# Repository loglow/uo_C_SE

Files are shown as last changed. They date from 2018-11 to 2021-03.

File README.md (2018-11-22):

# µo_C SE (uo_C, Ornament & Crime) Eurorack [Rev B]

## 8HP Eurorack module | Polymorphic CV generator

[μo_C SE](http://uoc-se.com) is a multi-purpose module in which a generic set of inputs and outputs are remapped on-the-fly through the use of a number of different built-in apps.

This re-engineered Eurorack module updates and simplifies the classic [Ornament & Crime](http://ornament-and-cri.me/) (aka o_C) design by miniaturizing the module from 14HP to 8HP and redesigning the front panel layout without eliminating any functionality.

Fully compatible with upstream o_C firmware. Includes power cable, mounting hardware, and a one-year warranty. Designed and built with care by [Tall Dog Electronics](http://tall-dog.com) in Western Massachusetts. Licensed [CC BY-NC-SA 4.0](https://creativecommons.org/licenses/by-nc-sa/4.0/) open source hardware.

- **Height:** 3U (128.5 mm)
- **Width:** 8HP (40.3 mm)
- **Depth:** 31 mm (with power)
- **+12V:** 85 mA (average)
- **-12V:** 10 mA (average)

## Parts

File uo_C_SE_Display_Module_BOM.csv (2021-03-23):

Reference | Quantity | Description | Manufacturer | Part Number | Digi-Key P/N
C1 | 1 | CAP CER 10UF 25V X5R 0805 | Taiyo Yuden | TMK212BBJ106KG-T | 587-2668-1-ND
C2 C3 C4 C5 C6 | 5 | CAP CER 2.2UF 10V X7R 0805 | Samsung | CL21B225KPFNNNE | 1276-1188-1-ND
H1 | 1 | .100" Flex Stack, High-Temp Flexible Board Stacker, Surface Mount | Samtec | HW-07-16-T-S-270-SM | N/A
H2 H3 | 2 | .100" Flex Stack, High-Temp Flexible Board Stacker, Surface Mount | Samtec | HW-03-16-T-S-270-SM | N/A
R1 | 1 | RES SMD 390K OHM 1% 1/8W 0805 | Yageo | RC0805FR-07390KL | 311-390KCRCT-ND
R2 R3 R4 | 3 | RES SMD 10K OHM 1% 1/8W 0805 | Yageo | RC0805FR-0710KL | 311-10.0KCRCT-ND
U1 | 1 | DISPLAY OLED 128X64 1.3" BLUE | WiseChip | UG-2864KSWLG03 | N/A

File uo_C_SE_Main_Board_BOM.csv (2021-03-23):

Reference | Quantity | Description | Manufacturer | Part Number | Digi-Key P/N
A1 | 1 | DISPLAY MODULE OLED | Tall Dog | TD-OCSE-B-DM | N/A
A2 | 1 | TEENSY 3.2 | PJRC | TEENSY32 | 1568-1231-ND
C1 C2 C5 C6 C7 C8 C12 C13 C14 C15 C16 C20 C21 C31 C34 | 15 | CAP CER 0.1UF 50V X7R 0603 | Samsung | CL10B104JB8NNNC | 1276-1033-1-ND
C3 C4 C9 | 3 | CAP CER 0.47UF 25V X7R 0603 | Samsung | CL10B474KA8NFNC | 1276-2082-1-ND
C10 C11 C24 C25 | 4 | CAP 10 UF 20% 25 V | Wurth Electronics | 865230440002 | 732-8259-1-ND
C17 C18 | 2 | CAP 22 UF 20% 25 V | Wurth Electronics | 865230443003 | 732-8260-1-ND
C19 C23 | 2 | CAP CER 1UF 25V X7R 0603 | Samsung | CL10B105KA8NNNC | 1276-1184-1-ND
C22 C26 C32 C33 | 4 | CAP CER 22PF 50V C0G/NP0 0603 | Samsung | CL10C220FB8NNNC | 1276-2224-1-ND
C27 C28 C29 C30 | 4 | CAP CER 560PF 50V C0G/NP0 0603 | Samsung | CL10C561JB8NNNC | 1276-1283-1-ND
D1 D2 | 2 | DIODE SCHOTTKY 40V 1A SOD123 | Diodes Incorporated | 1N5819HW-7-F | 1N5819HW-FDICT-ND
H1 | 1 | .100" Surface Mount Terminal Strip | Samtec | TSM-113-04-L-SV | N/A
H1-MATE | 1 | .100" Tiger Buy™ Low Profile Socket Strip | Samtec | SLW-113-01-L-S | N/A
H2 | 1 | .100" Surface Mount Terminal Strip | Samtec | TSM-114-04-L-SV | N/A
H2-MATE | 1 | .100" Tiger Buy™ Low Profile Socket Strip | Samtec | SLW-114-01-L-S | N/A
H3 | 1 | CONN HEADER VERT 10POS GOLD | On Shore Technology | 302-S101 | ED1543-ND
J1 J2 J3 J4 J5 J6 J7 J8 J9 J10 J11 J12 | 12 | 3.5MM JACK VERTICAL PCB MOUNT | Wenzhou QingPu | WQP-PJ398SM | N/A
L1 | 1 | FIXED IND 10UH 600MA 420 MOHM | TDK | NLCV32T-100K-PFR | 445-3654-1-ND
Q1 Q2 Q3 Q4 | 4 | TRANS NPN 40V 0.2A SOT23 | ON Semiconductor | MMBT3904LT1G | MMBT3904LT1GOSCT-ND
R1 | 1 | RES SMD 10K OHM 0.1% 1/10W 0603 | Susumu | RG1608P-103-B-T5 | RG16P10.0KBCT-ND
R2 R3 | 2 | RES SMD 47K OHM 0.1% 1/10W 0603 | Susumu | RG1608P-473-B-T5 | RG16P47.0KBCT-ND
R4 R5 | 2 | RES SMD 510 OHM 0.1% 1/10W 0603 | Susumu | RG1608P-511-B-T5 | RG16P510BCT-ND
R6 | 1 | RES SMD 2K OHM 0.1% 1/10W 0603 | Susumu | RG1608P-202-B-T5 | RG16P2.0KBCT-ND
R7 R14 R33 R34 | 4 | RES SMD 220 OHM 0.1% 1/10W 0603 | Susumu | RG1608P-221-B-T5 | RG16P220BCT-ND
R8 R21 R37 R38 | 4 | RES SMD 100K OHM 0.1% 1/10W 0603 | Susumu | RG1608P-104-B-T5 | RG16P100KBCT-ND
R9 R26 R39 R40 | 4 | RES SMD 24.9KOHM 0.1% 1/10W 0603 | Susumu | RG1608P-2492-B-T5 | RG16P24.9KBCT-ND
R10 R11 R12 R13 | 4 | RES SMD 75K OHM 0.1% 1/10W 0603 | Susumu | RG1608P-753-B-T5 | RG16P75.0KBCT-ND
R15 R16 R17 R18 R20 R28 R36 R42 | 8 | RES SMD 100K OHM 0.1% 1/10W 0603 | Susumu | RG1608P-104-B-T5 | RG16P100KBCT-ND
R19 R22 R23 R24 R25 R27 R35 R41 | 8 | RES SMD 33K OHM 0.1% 1/10W 0603 | Susumu | RG1608P-333-B-T5 | RG16P33.0KBCT-ND
R29 R30 R31 R32 | 4 | RES SMD 100 OHM 0.1% 1/10W 0603 | Susumu | RG1608P-101-B-T5 | RG16P100BCT-ND
S1 S4 | 2 | SWITCH TACTILE SPST-NO 0.05A 12V | E-Switch | TL1105DF160Q | EG1865-ND
S2 S3 | 2 | ENCODER ROTARY | Song Huei | ED1212S-24P-24C-25KC | N/A
U1 | 1 | IC DAC 16BIT QUAD-CH 16-TSSOP | Texas Instruments | DAC8565IAPW | 296-22924-5-ND
U2 | 1 | IC REG LINEAR 5V 800MA SOT223-4 | Texas Instruments | LM1117MPX-5.0/NOPB | LM1117MPX-5.0/NOPBCT-ND
U3 | 1 | IC REG LINEAR 3.3V 150MA TSOT5 | Analog Devices | ADP150AUJZ-3.3-R7 | ADP150AUJZ-3.3-R7CT-ND
U4 | 1 | IC VREF SHUNT 5V SOT23-3 | Texas Instruments | LM4040DIM3-5.0/NOPB | LM4040DIM3-5.0NS/NOPBCT-ND
U5 | 1 | IC OPAMP GP 1MHZ RRO 14TSSOP | Microchip Technology | MCP6004T-I/ST | MCP6004T-I/STCT-ND
U6 | 1 | IC OPAMP GP 10MHZ RRO 14TSSOP | Texas Instruments | OPA4172IPW | 296-42312-5-ND

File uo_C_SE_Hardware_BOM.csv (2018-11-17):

Description | Quantity
Window Lens Insert, Acrylic, 2 mm | 1
Thonkiconn Knurled Nut, Steel, M6 | 12
Threaded Hex Standoff, Brass, M2.5 x 10 mm | 2
Standoff Screw, Button Head, Hex Socket, M2.5 x 6 mm | 2
Standoff Screw, Flat Head, Hex Socket, M2.5 x 6 mm | 2

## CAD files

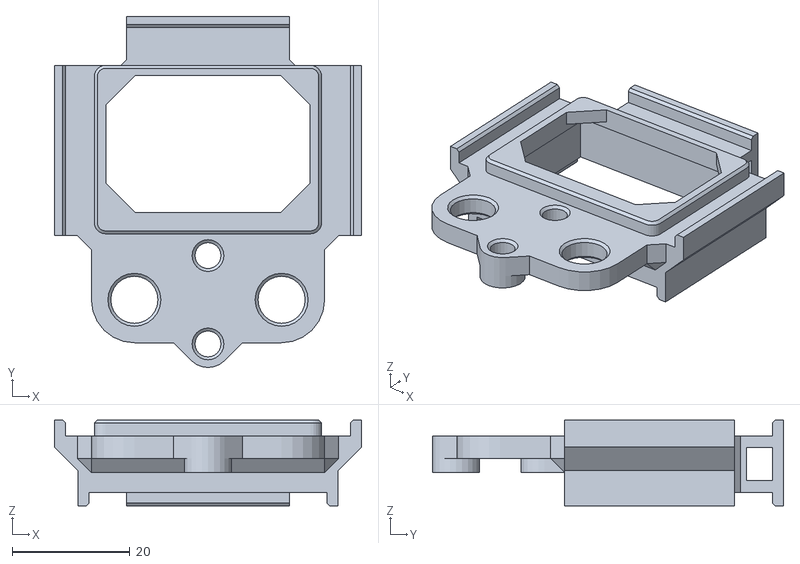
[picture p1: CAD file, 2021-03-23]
uo_C_SE_Assembly_Spacer.stl
52.2 x 59.6 x 14.6

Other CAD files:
uo_C_SE_Model.skp

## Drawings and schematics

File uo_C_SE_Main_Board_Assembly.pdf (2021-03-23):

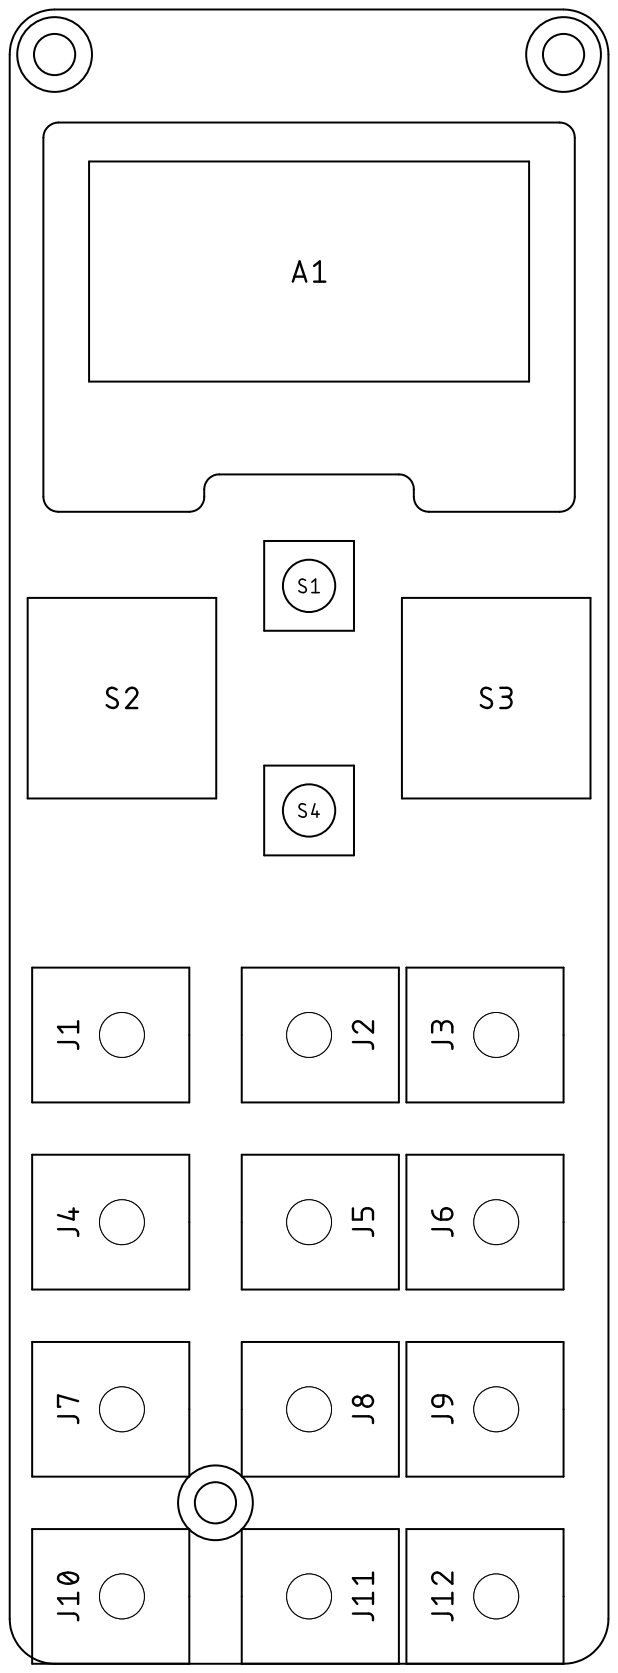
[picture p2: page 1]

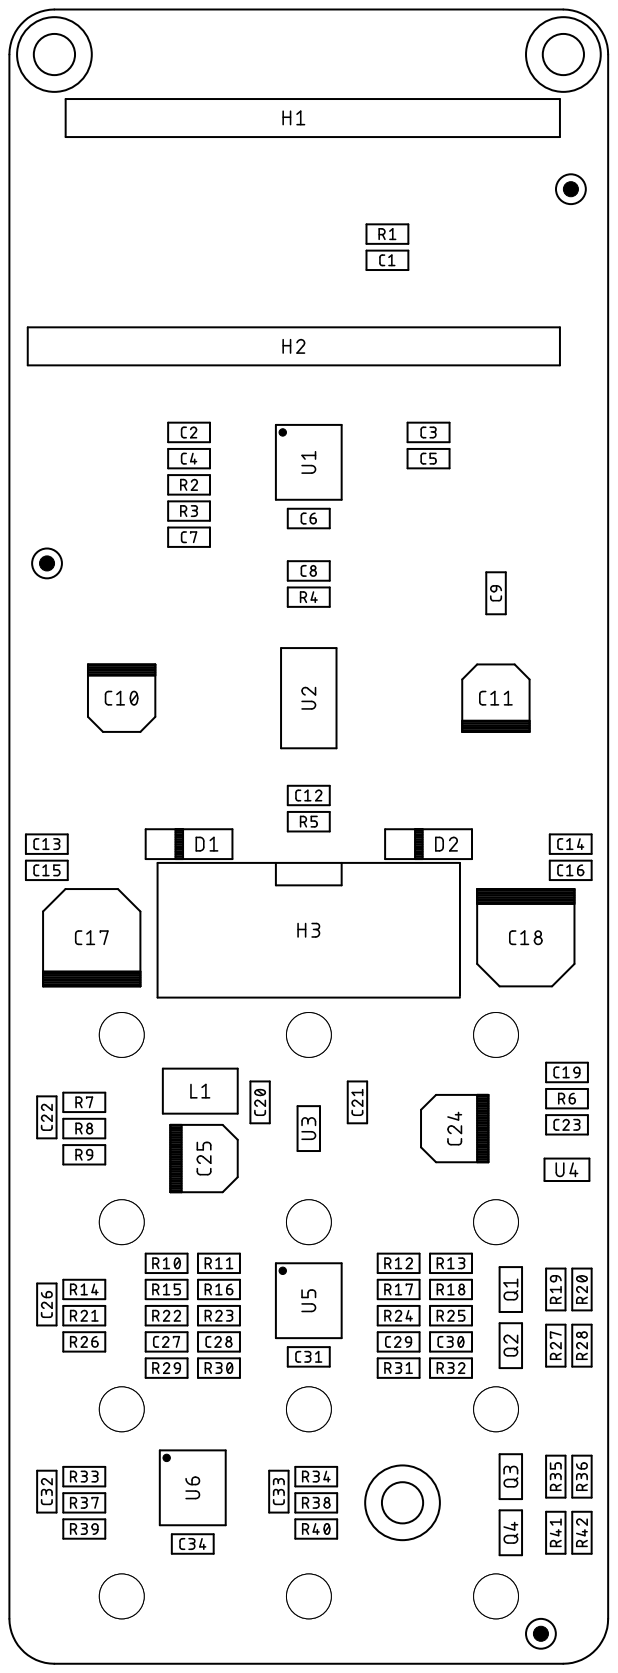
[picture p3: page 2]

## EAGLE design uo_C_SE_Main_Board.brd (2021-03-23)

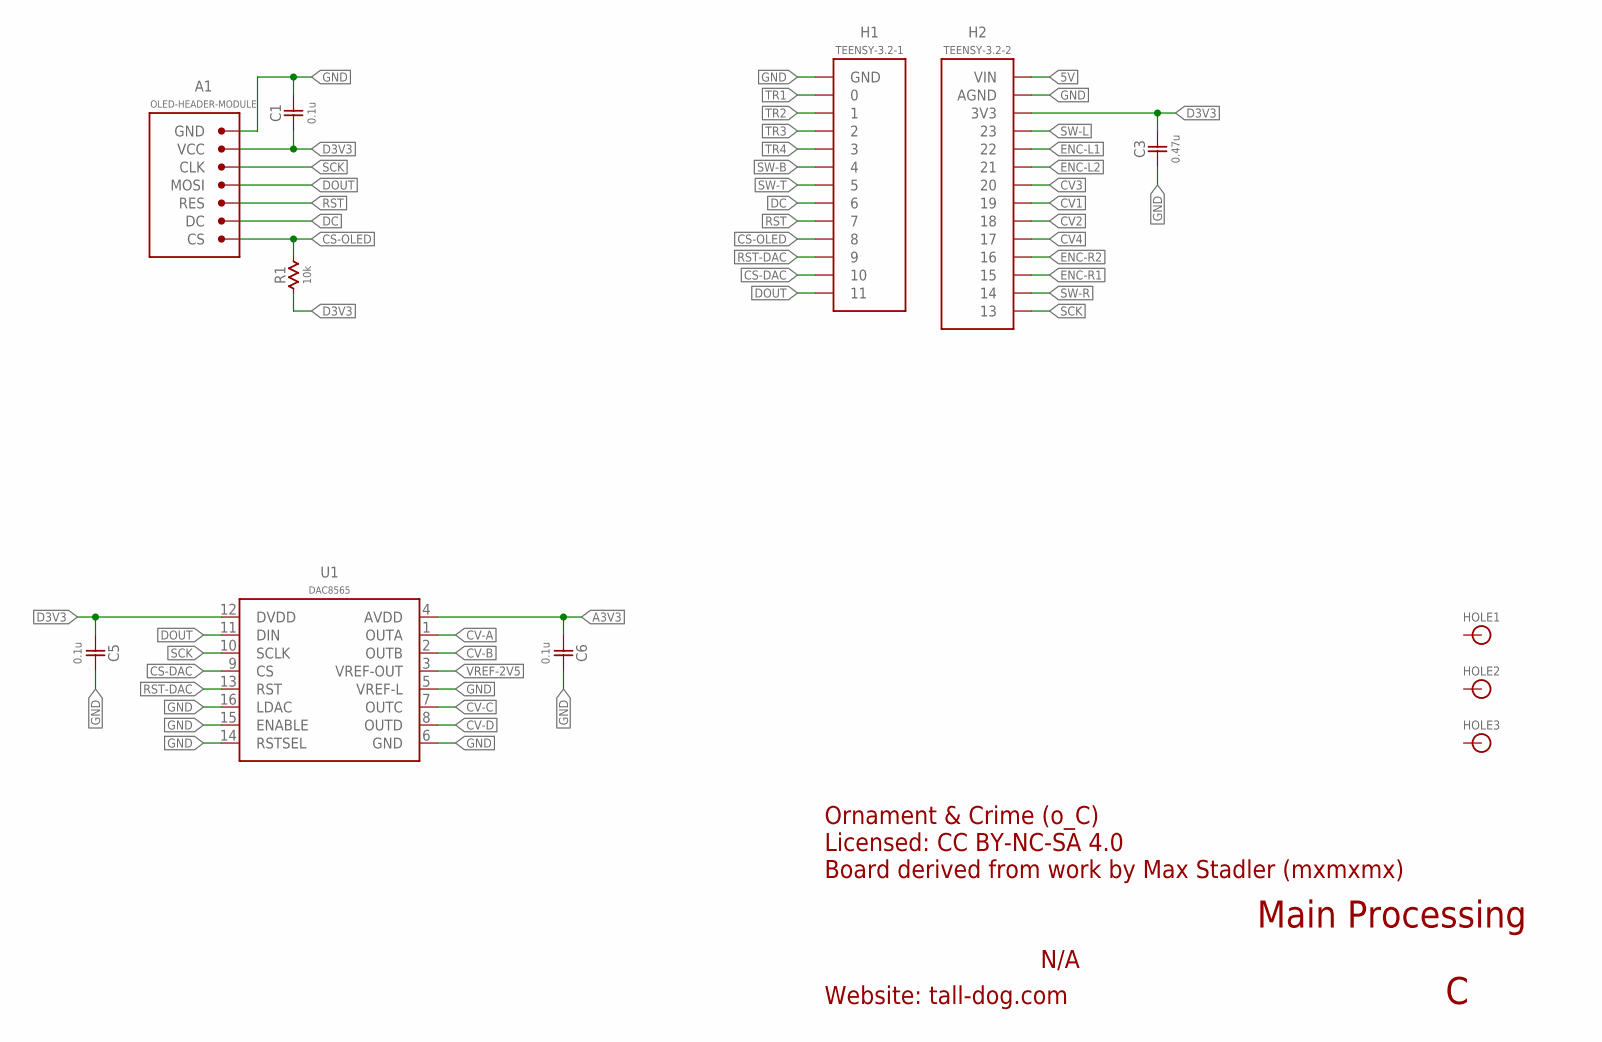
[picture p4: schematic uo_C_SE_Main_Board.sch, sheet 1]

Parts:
A1: OLED-HEADER-MODULE; DISPLAY-MODULE; MANUFACTURERPARTNUMBER TD-OCSE-B-DM
C1, C5, C6: 0.1u; 0603-NP; MANUFACTURERPARTNUMBER CL10B104JB8NNNC
C3: 0.47u; 0603-NP; MANUFACTURERPARTNUMBER CL10B474KA8NFNC
H1: TEENSY-3.2-1; SMD-0.1-1X13; MANUFACTURERPARTNUMBER TSM-113-04-L-SV
H2: TEENSY-3.2-2; SMD-0.1-1X14; MANUFACTURERPARTNUMBER TSM-114-04-L-SV
HOLE1, HOLE2, HOLE3: HOLE; M2.5-HOLE
R1: 10k; 0603-NP; MANUFACTURERPARTNUMBER ERJ-3EKF1002V
U1: DAC8565; TSSOP-16; MANUFACTURERPARTNUMBER DAC8565IAPW

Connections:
5V: H2.1 (VIN); also elsewhere on the board
A3V3: C6.1, U1.4 (AVDD); also elsewhere on the board
CS-DAC: H1.12 (10), U1.9 (CS)
CS-OLED: A1.7 (CS), H1.10 (8), R1.2
CV1: H2.8 (19); also elsewhere on the board
CV2: H2.9 (18); also elsewhere on the board
CV3: H2.7 (20); also elsewhere on the board
CV4: H2.10 (17); also elsewhere on the board
CV-A: U1.1 (OUTA); also elsewhere on the board
CV-B: U1.2 (OUTB); also elsewhere on the board
CV-C: U1.7 (OUTC); also elsewhere on the board
CV-D: U1.8 (OUTD); also elsewhere on the board
D3V3: A1.2 (VCC), C1.1, C3.2, C5.1, H2.3 (3V3), R1.1, U1.12 (DVDD)
DC: A1.6 (DC), H1.8 (6)
DOUT: A1.4 (MOSI), H1.13 (11), U1.11 (DIN)
ENC-L1: H2.5 (22); also elsewhere on the board
ENC-L2: H2.6 (21); also elsewhere on the board
ENC-R1: H2.12 (15); also elsewhere on the board
ENC-R2: H2.11 (16); also elsewhere on the board
GND: A1.1 (GND), A1.G1 (GND), A1.G2 (GND), A1.G3 (GND), A1.G4 (GND), A1.G5 (GND), A1.G6 (GND), C1.2, C3.1, C5.2, C6.2, H1.1 (GND), H2.2 (AGND), U1.5 (VREF-L), U1.6 (GND), U1.14 (RSTSEL), U1.15 (ENABLE), U1.16 (LDAC); also elsewhere on the board
RST: A1.5 (RES), H1.9 (7)
RST-DAC: H1.11 (9), U1.13 (RST)
SCK: A1.3 (CLK), H2.14 (13), U1.10 (SCLK)
SW-B: H1.6 (4); also elsewhere on the board
SW-L: H2.4 (23); also elsewhere on the board
SW-R: H2.13 (14); also elsewhere on the board
SW-T: H1.7 (5); also elsewhere on the board
TR1: H1.2 (0); also elsewhere on the board
TR2: H1.3 (1); also elsewhere on the board
TR3: H1.4 (2); also elsewhere on the board
TR4: H1.5 (3); also elsewhere on the board
VREF-2V5: U1.3 (VREF-OUT); also elsewhere on the board

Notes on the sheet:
Ornament & Crime (o_C) Licensed: CC BY-NC-SA 4.0 Board derived from work by Max Stadler (mxmxmx)
Website: tall-dog.com
N/A
Main Processing

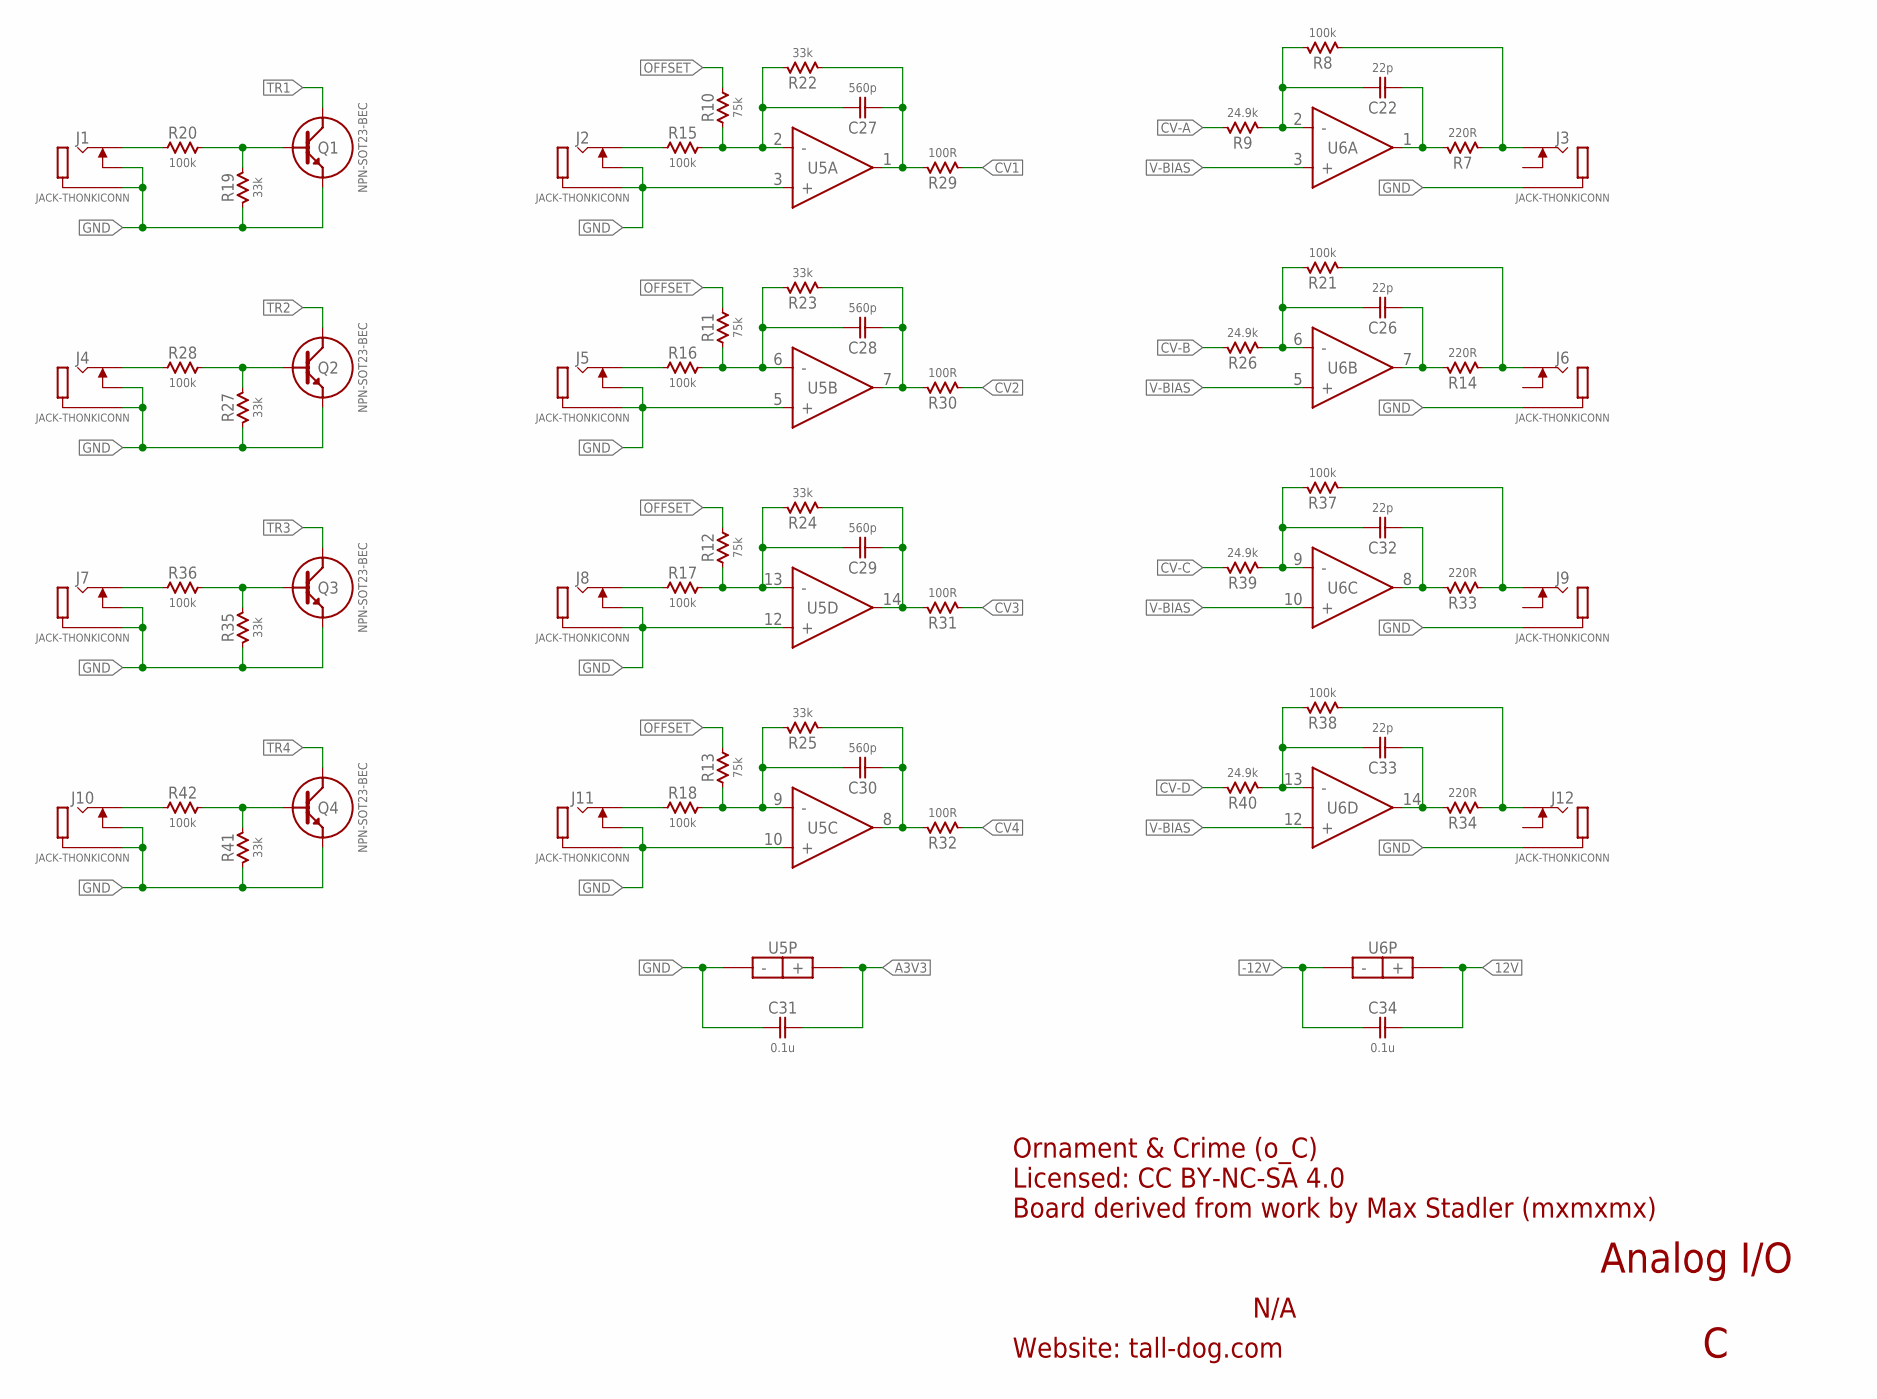
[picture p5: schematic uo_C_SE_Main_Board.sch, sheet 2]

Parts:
C22, C26, C32, C33: 22p; 0603-NP; MANUFACTURERPARTNUMBER CL10C220FB8NNWC
C27, C28, C29, C30: 560p; 0603-NP; MANUFACTURERPARTNUMBER CL10C561JB8NNNC
C31, C34: 0.1u; 0603-NP; MANUFACTURERPARTNUMBER CL10B104JB8NNNC
J1: JACK-THONKICONN; JACK; MANUFACTURERPARTNUMBER WQP-PJ398SM
J2, J3, J4, J5, J6, J7, J8, J9, J10, J11, J12: JACK-THONKICONN; JACK
Q1, Q2, Q3, Q4: NPN-SOT23-BEC; SOT-23-3
R7, R14, R33, R34: 220R; 0603-NP; MANUFACTURERPARTNUMBER ERJ-3EKF2200V
R8, R15, R16, R17, R18, R20, R21, R28, R36, R37, R38, R42: 100k; 0603-NP; MANUFACTURERPARTNUMBER ERA-3AEB104V
R9, R26, R39, R40: 24.9k; 0603-NP; MANUFACTURERPARTNUMBER ERA-3AEB2492V
R10, R11, R12, R13: 75k; 0603-NP; MANUFACTURERPARTNUMBER ERJ-3EKF7502V
R19, R22, R23, R24, R25, R27, R35, R41: 33k; 0603-NP; MANUFACTURERPARTNUMBER ERJ-3EKF3302V
R29, R30, R31, R32: 100R; 0603-NP; MANUFACTURERPARTNUMBER ERJ-3EKF1000V
U5: MCP6004-TSSOP-14; TSSOP-14
U6: OPA4172; TSSOP-14

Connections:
12V: C34.1, U6.4 (+); also elsewhere on the board
-12V: C34.2, U6.11 (-); also elsewhere on the board
A3V3: C31.1, U5.4 (+); also elsewhere on the board
CV1: R29.2; also elsewhere on the board
CV2: R30.2; also elsewhere on the board
CV3: R31.2; also elsewhere on the board
CV4: R32.2; also elsewhere on the board
CV-A: R9.1; also elsewhere on the board
CV-B: R26.1; also elsewhere on the board
CV-C: R39.1; also elsewhere on the board
CV-D: R40.1; also elsewhere on the board
GND: C31.2, J1.P1 (1), J1.P2 (2), J2.P1 (1), J2.P2 (2), J3.P1 (1), J4.P1 (1), J4.P2 (2), J5.P1 (1), J5.P2 (2), J6.P1 (1), J7.P1 (1), J7.P2 (2), J8.P1 (1), J8.P2 (2), J9.P1 (1), J10.P1 (1), J10.P2 (2), J11.P1 (1), J11.P2 (2), J12.P1 (1), Q1.2 (E), Q2.2 (E), Q3.2 (E), Q4.2 (E), R19.2, R27.2, R35.2, R41.2, U5.3 (+), U5.5 (+), U5.10 (+), U5.11 (-), U5.12 (+); also elsewhere on the board
unnamed: J11.P3 (3), R18.1
unnamed: J8.P3 (3), R17.1
unnamed: J5.P3 (3), R16.1
unnamed: J2.P3 (3), R15.1
unnamed: J1.P3 (3), R20.1
unnamed: C27.1, R10.1, R15.2, R22.1, U5.2 (-)
unnamed: Q1.1 (B), R19.1, R20.2
unnamed: C28.1, R11.1, R16.2, R23.1, U5.6 (-)
unnamed: C29.1, R12.1, R17.2, R24.1, U5.13 (-)
unnamed: C22.2, R8.1, R9.2, U6.2 (-)
unnamed: C30.1, R13.1, R18.2, R25.1, U5.9 (-)
unnamed: J4.P3 (3), R28.1
unnamed: C27.2, R22.2, R29.1, U5.1 (OUT)
unnamed: C28.2, R23.2, R30.1, U5.7 (OUT)
unnamed: Q2.1 (B), R27.1, R28.2
unnamed: C29.2, R24.2, R31.1, U5.14 (OUT)
unnamed: C30.2, R25.2, R32.1, U5.8 (OUT)
unnamed: C26.2, R21.1, R26.2, U6.6 (-)
unnamed: J7.P3 (3), R36.1
unnamed: Q3.1 (B), R35.1, R36.2
unnamed: C32.2, R37.1, R39.2, U6.9 (-)
unnamed: C33.2, R38.1, R40.2, U6.13 (-)
unnamed: J10.P3 (3), R42.1
unnamed: Q4.1 (B), R41.1, R42.2
unnamed: C22.1, R7.1, U6.1 (OUT)
unnamed: C26.1, R14.1, U6.7 (OUT)
unnamed: C32.1, R33.1, U6.8 (OUT)
unnamed: C33.1, R34.1, U6.14 (OUT)
unnamed: J3.P3 (3), R7.2, R8.2
unnamed: J6.P3 (3), R14.2, R21.2
unnamed: J9.P3 (3), R33.2, R37.2
unnamed: J12.P3 (3), R34.2, R38.2
OFFSET: R10.2, R11.2, R12.2, R13.2; also elsewhere on the board
TR1: Q1.3 (C); also elsewhere on the board
TR2: Q2.3 (C); also elsewhere on the board
TR3: Q3.3 (C); also elsewhere on the board
TR4: Q4.3 (C); also elsewhere on the board
V-BIAS: U6.3 (+), U6.5 (+), U6.10 (+), U6.12 (+); also elsewhere on the board

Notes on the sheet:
Ornament & Crime (o_C) Licensed: CC BY-NC-SA 4.0 Board derived from work by Max Stadler (mxmxmx)
Website: tall-dog.com
N/A
Analog I/O

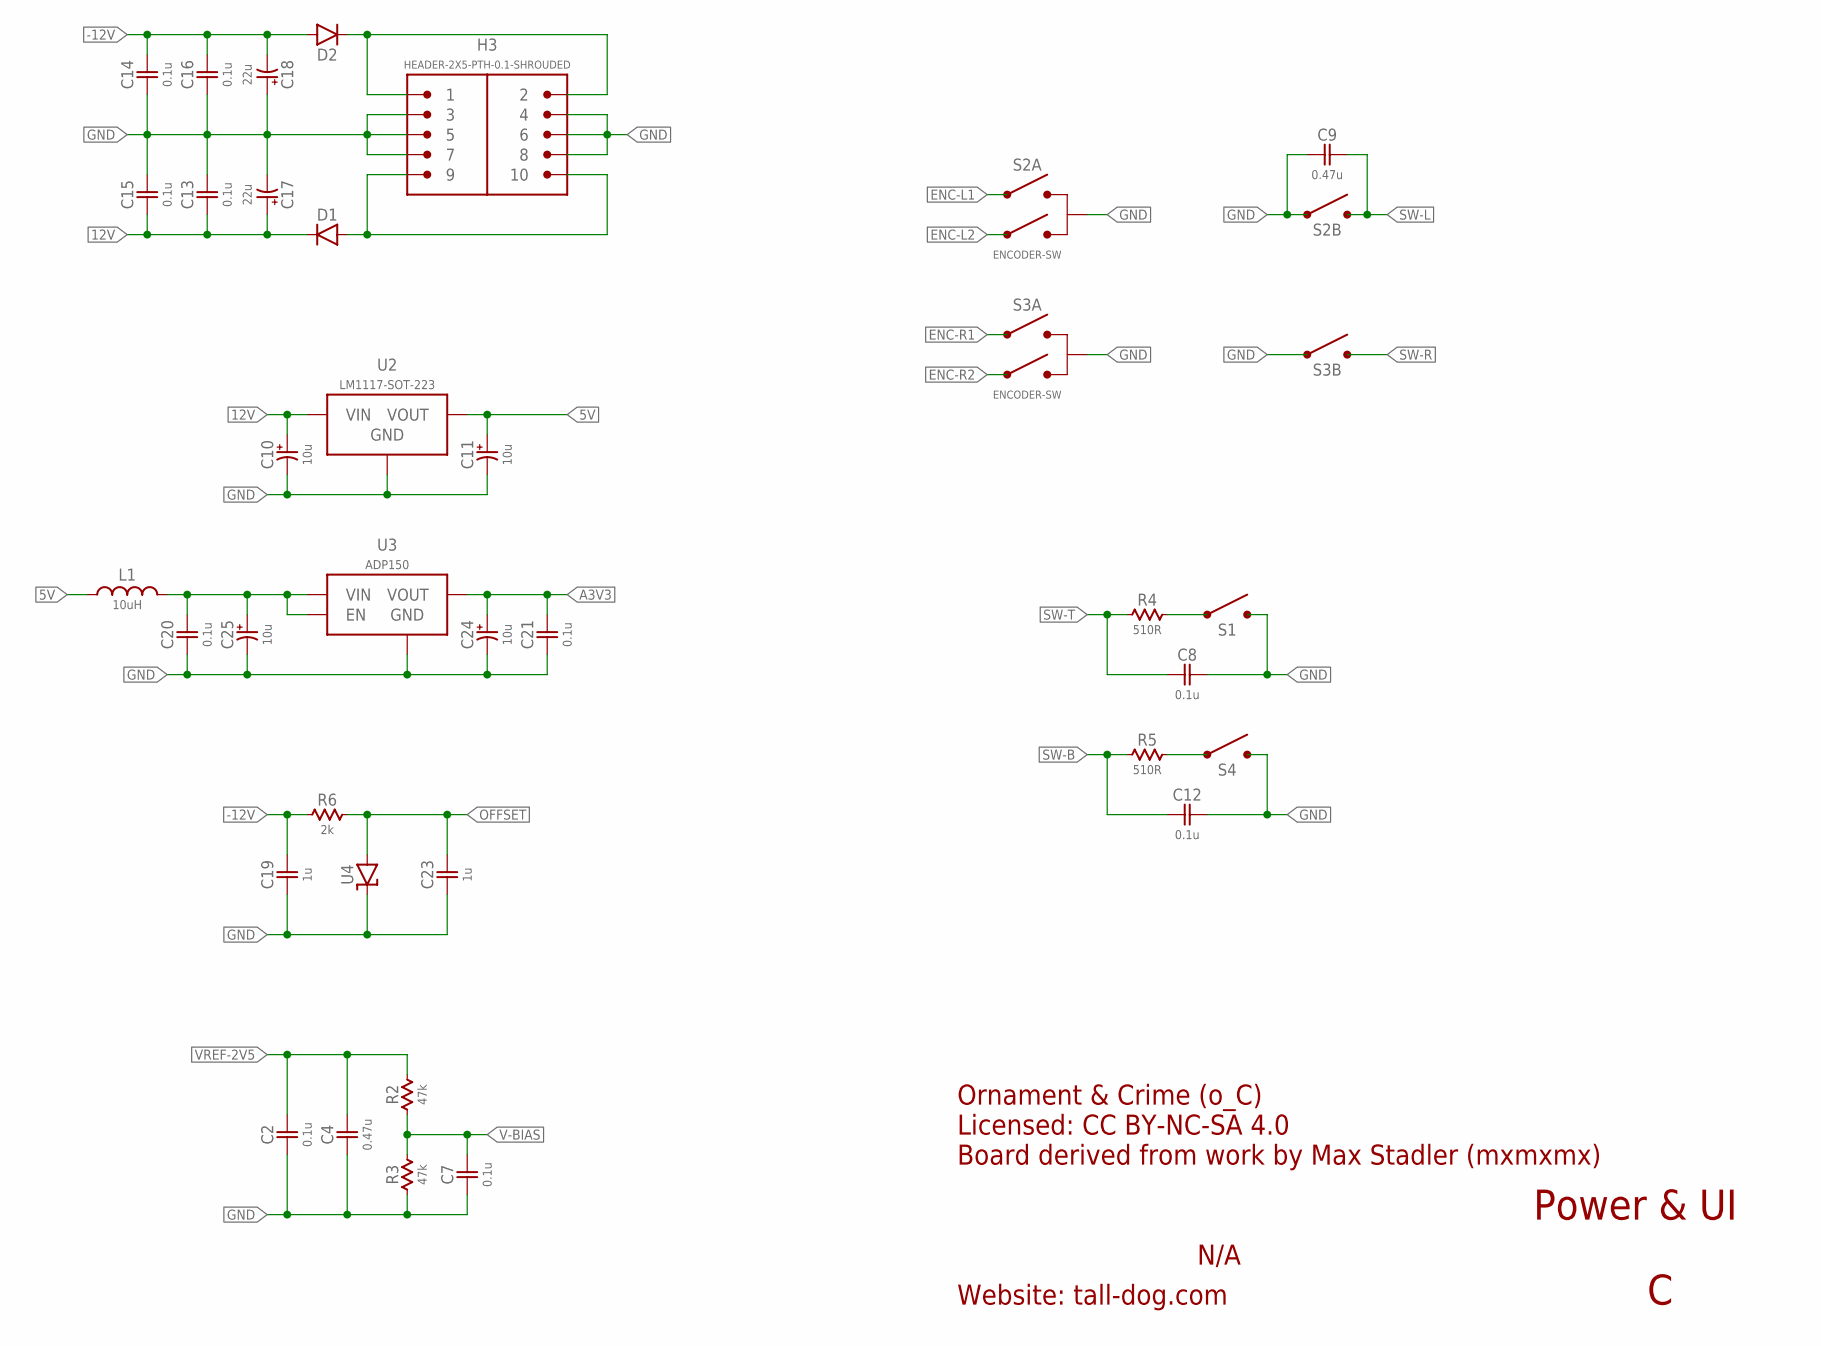
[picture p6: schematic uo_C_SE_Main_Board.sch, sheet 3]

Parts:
C2, C7, C8, C12, C13, C14, C15, C16, C20, C21: 0.1u; 0603-NP; MANUFACTURERPARTNUMBER CL10B104JB8NNNC
C4, C9: 0.47u; 0603-NP; MANUFACTURERPARTNUMBER CL10B474KA8NFNC
C10, C11, C24, C25: 10u; ELECTRO-SMD-4.3MM; MANUFACTURERPARTNUMBER 865230440002
C17, C18: 22u; ELECTRO-SMD-6.6MM; MANUFACTURERPARTNUMBER 865230443003
C19, C23: 1u; 0603-NP; MANUFACTURERPARTNUMBER CL10B105KA8NNNC
D1, D2: DIODE-SOD123; SOD-123
H3: HEADER-2X5-PTH-0.1-SHROUDED; PTH-0.1-2X5-SHROUDED
L1: 10uH; 1210-NP; MANUFACTURERPARTNUMBER NLCV32T-100K-PFR
R2, R3: 47k; 0603-NP; MANUFACTURERPARTNUMBER ERJ-3EKF4702V
R4, R5: 510R; 0603-NP; MANUFACTURERPARTNUMBER ERJ-3EKF5100V
R6: 2k; 0603-NP; MANUFACTURERPARTNUMBER ERJ-3EKF2001V
S1, S4: SPST-PTH; TL1105
S2, S3: ENCODER-SW; ENCODER-EC12E
U2: LM1117-SOT-223; SOT-223
U3: ADP150; SOT-23-5
U4: LM4040-SOT-23; SOT-23-3

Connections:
5V: C11.A (POS), L1.1, U2.2 (VOUT), U2.4 (VOUT); also elsewhere on the board
12V: C10.A (POS), C13.1, C15.1, C17.A (POS), D1.C, U2.3 (VIN); also elsewhere on the board
-12V: C14.2, C16.2, C18.C (NEG), C19.1, D2.A, R6.1; also elsewhere on the board
A3V3: C21.2, C24.A (POS), U3.5 (VOUT); also elsewhere on the board
ENC-L1: S2.B; also elsewhere on the board
ENC-L2: S2.A; also elsewhere on the board
ENC-R1: S3.B; also elsewhere on the board
ENC-R2: S3.A; also elsewhere on the board
GND: C2.2, C4.2, C7.2, C8.2, C9.1, C10.C (NEG), C11.C (NEG), C12.2, C13.2, C14.1, C15.2, C16.1, C17.C (NEG), C18.A (POS), C19.2, C20.1, C21.1, C23.2, C24.C (NEG), C25.C (NEG), H3.3, H3.4, H3.5, H3.6, H3.7, H3.8, R3.1, S1.3 (2), S1.4 (2), S2.C, S2.D (1), S3.C, S3.D (1), S4.3 (2), S4.4 (2), U2.1 (GND), U3.2 (GND), U4.1 (C); also elsewhere on the board
unnamed: C20.2, C25.A (POS), L1.2, U3.1 (VIN), U3.3 (EN)
unnamed: D2.C, H3.1, H3.2
unnamed: D1.A, H3.9, H3.10
unnamed: R4.2, S1.1, S1.2 (1)
unnamed: R5.2, S4.1, S4.2 (1)
OFFSET: C23.1, R6.2, U4.2 (A); also elsewhere on the board
SW-B: C12.1, R5.1; also elsewhere on the board
SW-L: C9.2, S2.E (2); also elsewhere on the board
SW-R: S3.E (2); also elsewhere on the board
SW-T: C8.1, R4.1; also elsewhere on the board
V-BIAS: C7.1, R2.1, R3.2; also elsewhere on the board
VREF-2V5: C2.1, C4.1, R2.2; also elsewhere on the board

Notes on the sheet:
Ornament & Crime (o_C) Licensed: CC BY-NC-SA 4.0 Board derived from work by Max Stadler (mxmxmx)
Website: tall-dog.com
N/A
Power & UI

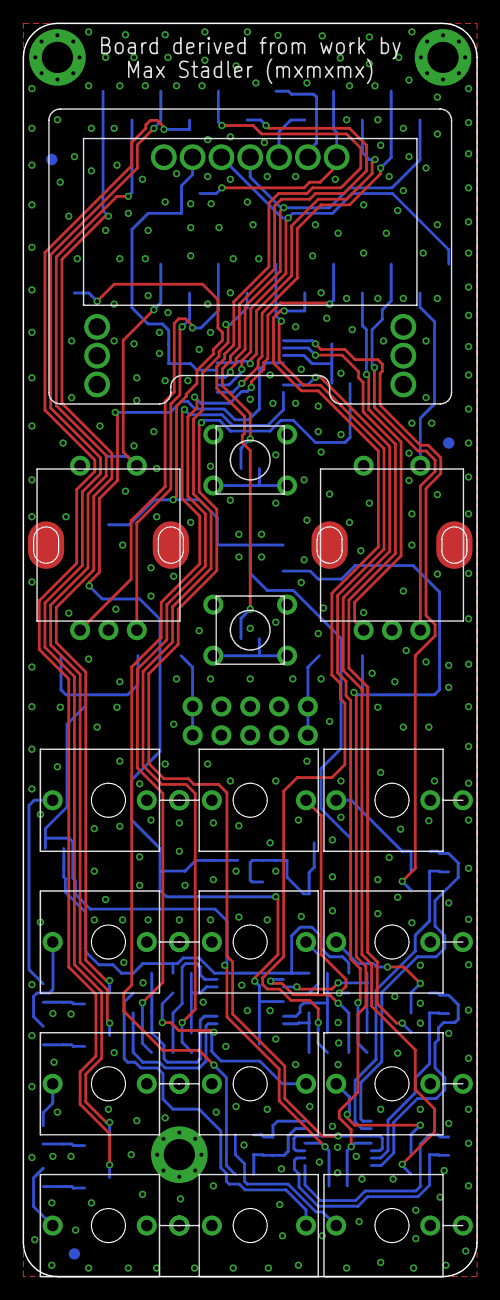
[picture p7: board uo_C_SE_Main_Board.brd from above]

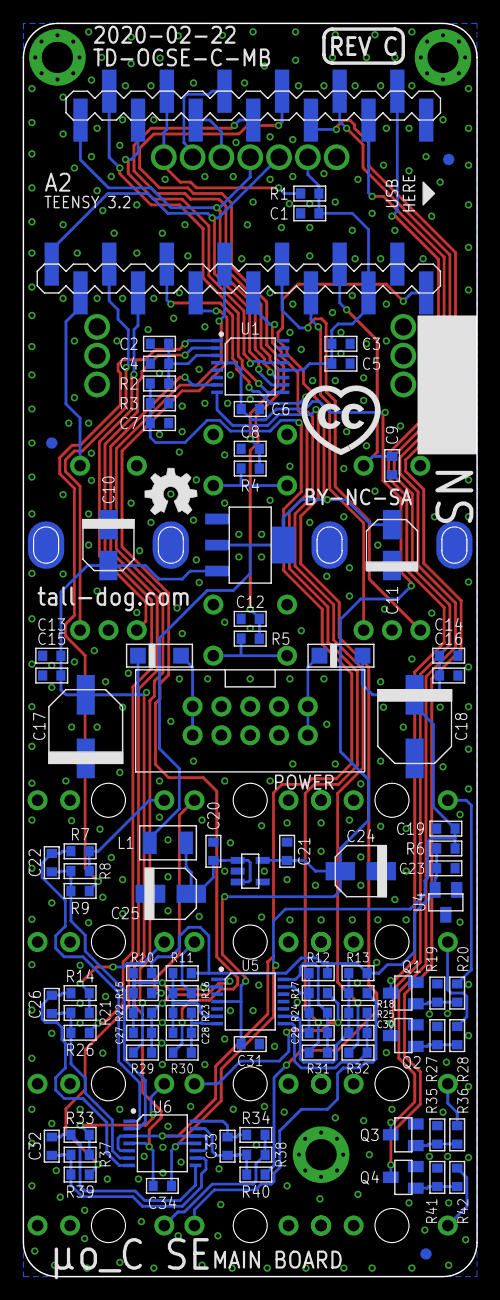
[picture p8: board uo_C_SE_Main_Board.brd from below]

Board: 2 copper layers, 40.0 x 110.5 mm, 118 parts (98 on the bottom side), 73 nets.

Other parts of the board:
U$1: LOGO-CC
U$2: LOGO-OSH
U$3: LOGO-REV
U$4, U$5, U$6: FIDUCIAL

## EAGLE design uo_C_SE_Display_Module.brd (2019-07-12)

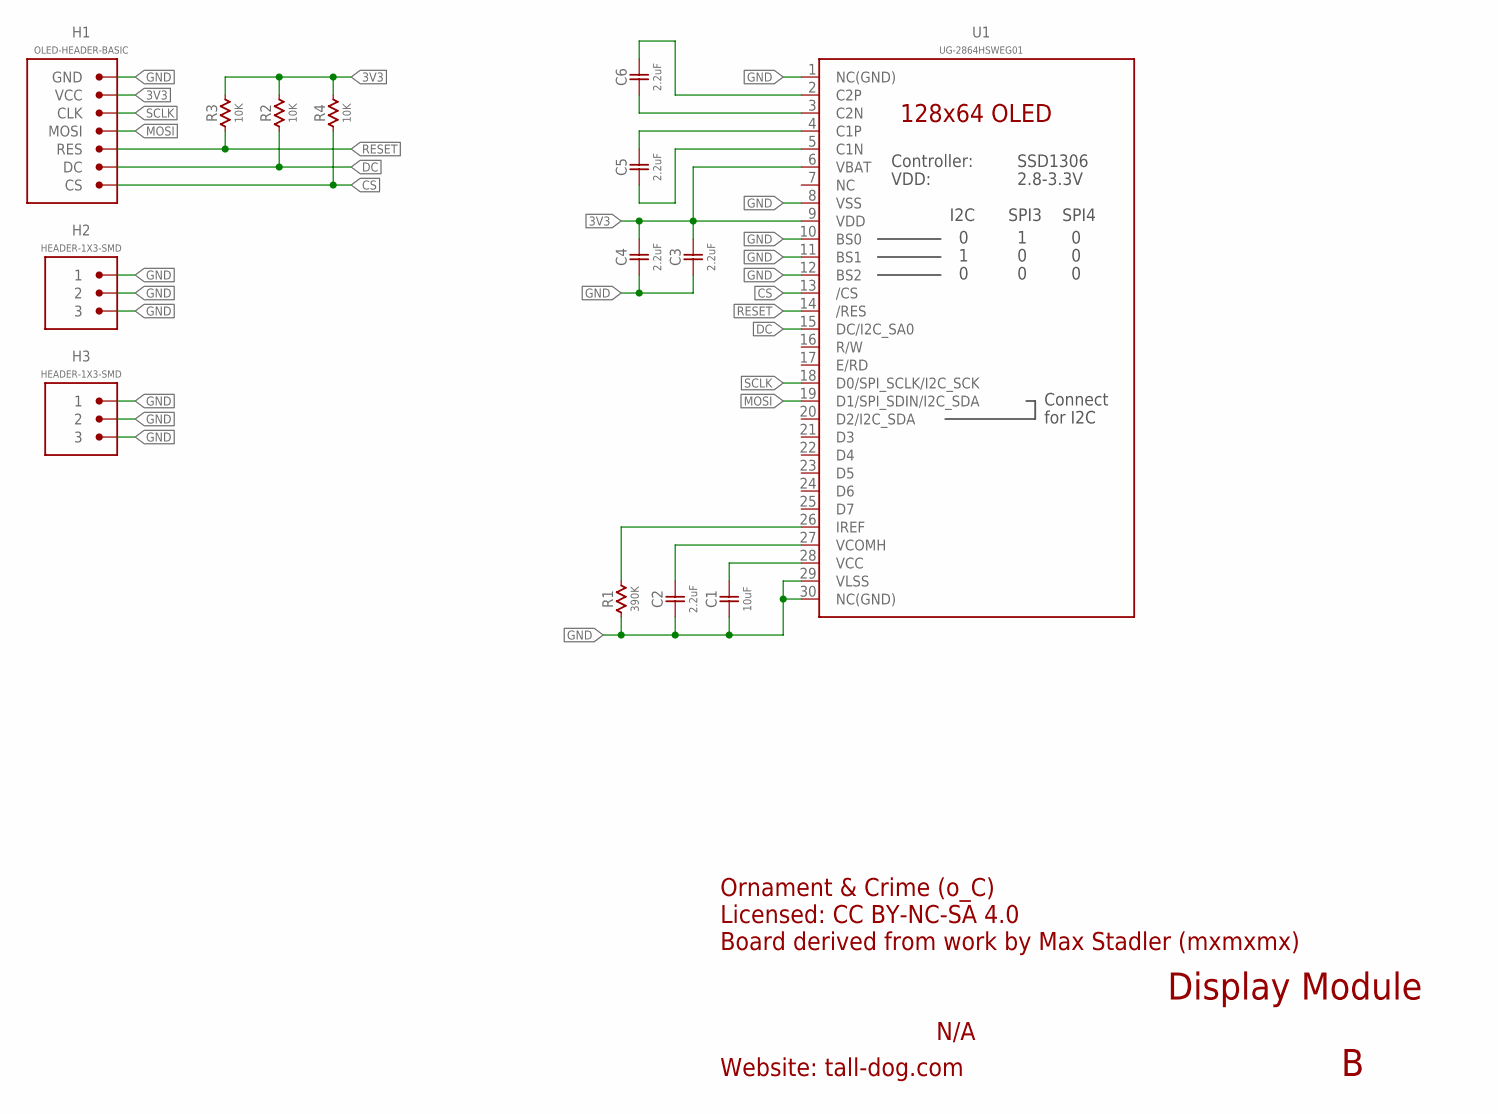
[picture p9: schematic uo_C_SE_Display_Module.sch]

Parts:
C1: 10uF; 0805-NP
C2, C3, C4, C5, C6: 2.2uF; 0805-NP
H1: OLED-HEADER-BASIC; SMD-0.1-1X7
H2, H3: HEADER-1X3-SMD; SMD-0.1-1X3
R1: 390K; 0805-NP
R2, R3, R4: 10K; 0805-NP
U1: UG-2864HSWEG01; OLED-128X64

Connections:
3V3: C3.2, C4.2, H1.2 (VCC), R2.2, R3.2, R4.2, U1.6 (VBAT), U1.9 (VDD)
CS: H1.7 (CS), R4.1, U1.13 (/CS)
DC: H1.6 (DC), R2.1, U1.15 (DC/I2C_SA0)
GND: C1.1, C2.1, C3.1, C4.1, H1.1 (GND), H2.1, H2.2, H2.3, H3.1, H3.2, H3.3, R1.1, U1.1 (NC(GND)), U1.8 (VSS), U1.10 (BS0), U1.11 (BS1), U1.12 (BS2), U1.29 (VLSS), U1.30 (NC(GND))
MOSI: H1.4 (MOSI), U1.19 (D1/SPI_SDIN/I2C_SDA)
unnamed: R1.2, U1.26 (IREF)
unnamed: C6.2, U1.2 (C2P)
unnamed: C6.1, U1.3 (C2N)
unnamed: C5.2, U1.4 (C1P)
unnamed: C5.1, U1.5 (C1N)
unnamed: C1.2, U1.28 (VCC)
unnamed: C2.2, U1.27 (VCOMH)
RESET: H1.5 (RES), R3.1, U1.14 (/RES)
SCLK: H1.3 (CLK), U1.18 (D0/SPI_SCLK/I2C_SCK)

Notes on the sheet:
Ornament & Crime (o_C) Licensed: CC BY-NC-SA 4.0 Board derived from work by Max Stadler (mxmxmx)
Website: tall-dog.com
N/A
Display Module

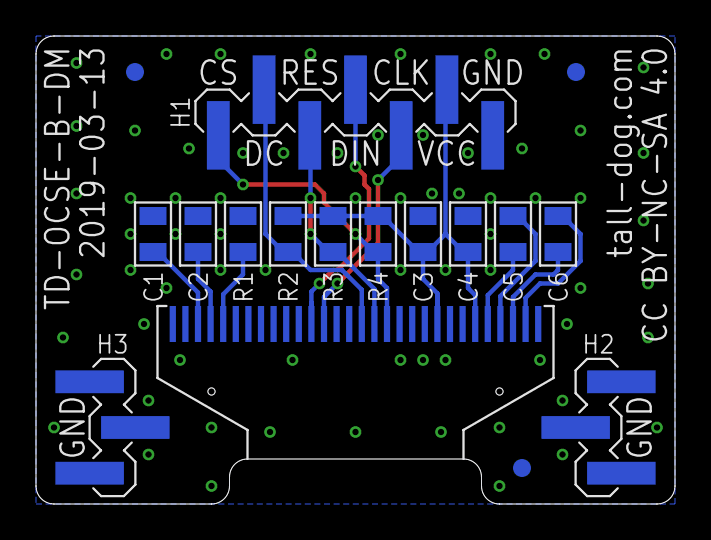
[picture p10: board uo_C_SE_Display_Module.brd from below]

Board: 2 copper layers, 35.5 x 26.0 mm, 17 parts (16 on the bottom side), 14 nets.

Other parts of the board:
U$1, U$2, U$3: FIDUCIAL

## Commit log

2018-11-17 initial commit, revision B production
    [uo_C_SE_Assembly_Spacer.stl, uo_C_SE_Assembly_Template.brd, uo_C_SE_Display_Module.brd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]
2019-07-12 assembly process updates
    [uo_C_SE_Assembly_Spacer.stl, uo_C_SE_Assembly_Template.brd, uo_C_SE_Display_Module.brd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]
2021-03-23 Revision C
    [uo_C_SE_Assembly_Spacer.stl, uo_C_SE_Assembly_Template.brd, uo_C_SE_Display_Module_BOM.csv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]
